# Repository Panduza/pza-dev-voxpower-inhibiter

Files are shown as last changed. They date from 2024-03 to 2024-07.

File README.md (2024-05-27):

# pza-dev-voxpower-inhibiter

The device will serve as the link between the Panduza platform and the Voxpower to command the inhibiters. The platform will use a serial communication with the board and the board will deliver 5V to the desired channel. 

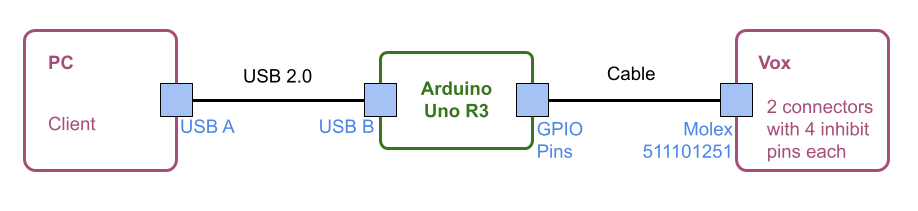
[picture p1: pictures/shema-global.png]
global representation of the product


### `[VOX_INHIB_0000_00]` - Board used

The board used **must** be an Arduino UNO R3

### `[VOX_INHIB_0010_00]` - Cables

The connection between the PC and the Arduino **must** be via an USB 2.0 A to B.

The connection between the Arduino and the Vox Power **must** be via simple cables linked to the connectors.

### `[VOX_INHIB_0020_00]` - Connectors

The connectors for the Vox Power **must** be :

| Manufacturer | Housing | Terminal  |
| :---: | :---: | :---: |
| Molex | 511101251 | 503948051 |

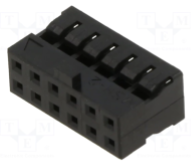
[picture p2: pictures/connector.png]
connector


### `[VOX_INHIB_0030_00]` - Pinout

The inhibiter pinout **must** be :

| Arduino | D2 | D3 | D4 | D5 | A0 | A1 | A2 | A3 | GND  |
| :--- | :--: | :--: | :--: | :--: | :--: | :--: | :--: | :--: | :--: |
| Vox | INH1 | INH2 | INH3 | INH4 | INH5 | INH6 | INH7 | INH8 | COM  |

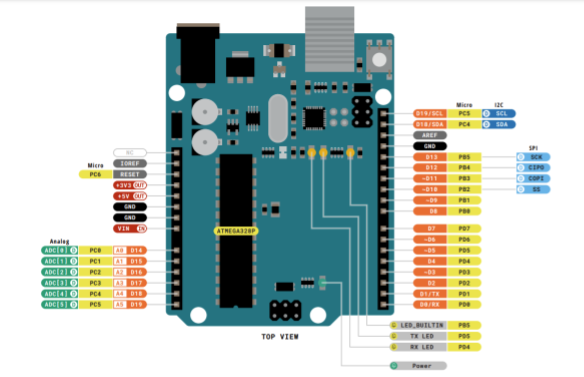
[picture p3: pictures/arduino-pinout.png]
arduino-pinout

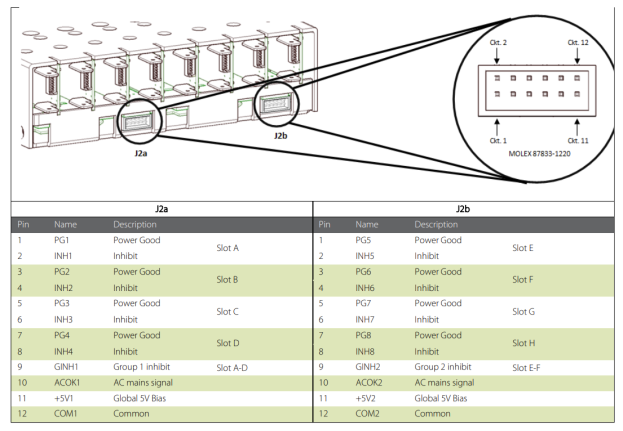
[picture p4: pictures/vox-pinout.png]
vox-pinout


### `[VOX_INHIB_0040_00]` - USB configuration

The USB configuration **must** be done with a serial link and a baud rate of 115200.

### `[VOX_INHIB_0050_10]` - Communication protocol

The protocol to specify the action (inhibit or enable or state) and the channel N **must** be :
```bash
"I" N

"E" N

"S" N
```

When receiving a "S" the Arduino **must** return the state "H" or "L" of the specified pin.
When changing the state, the Arduino **must** return the state "H" or "L" of the specified pin.

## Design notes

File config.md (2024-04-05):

# Conf

To use thee VoxposerInhibiter make sure that the /etc/panduza/tree.json contains\
\
tree.json
```bash
{
    "devices": [
        {
            "ref": "Panduza.VoxpowerInhibiter",
            "name": "test",
            "settings": 
            {
                "number_of_channel": 1
            }
        }
    ]
}
```

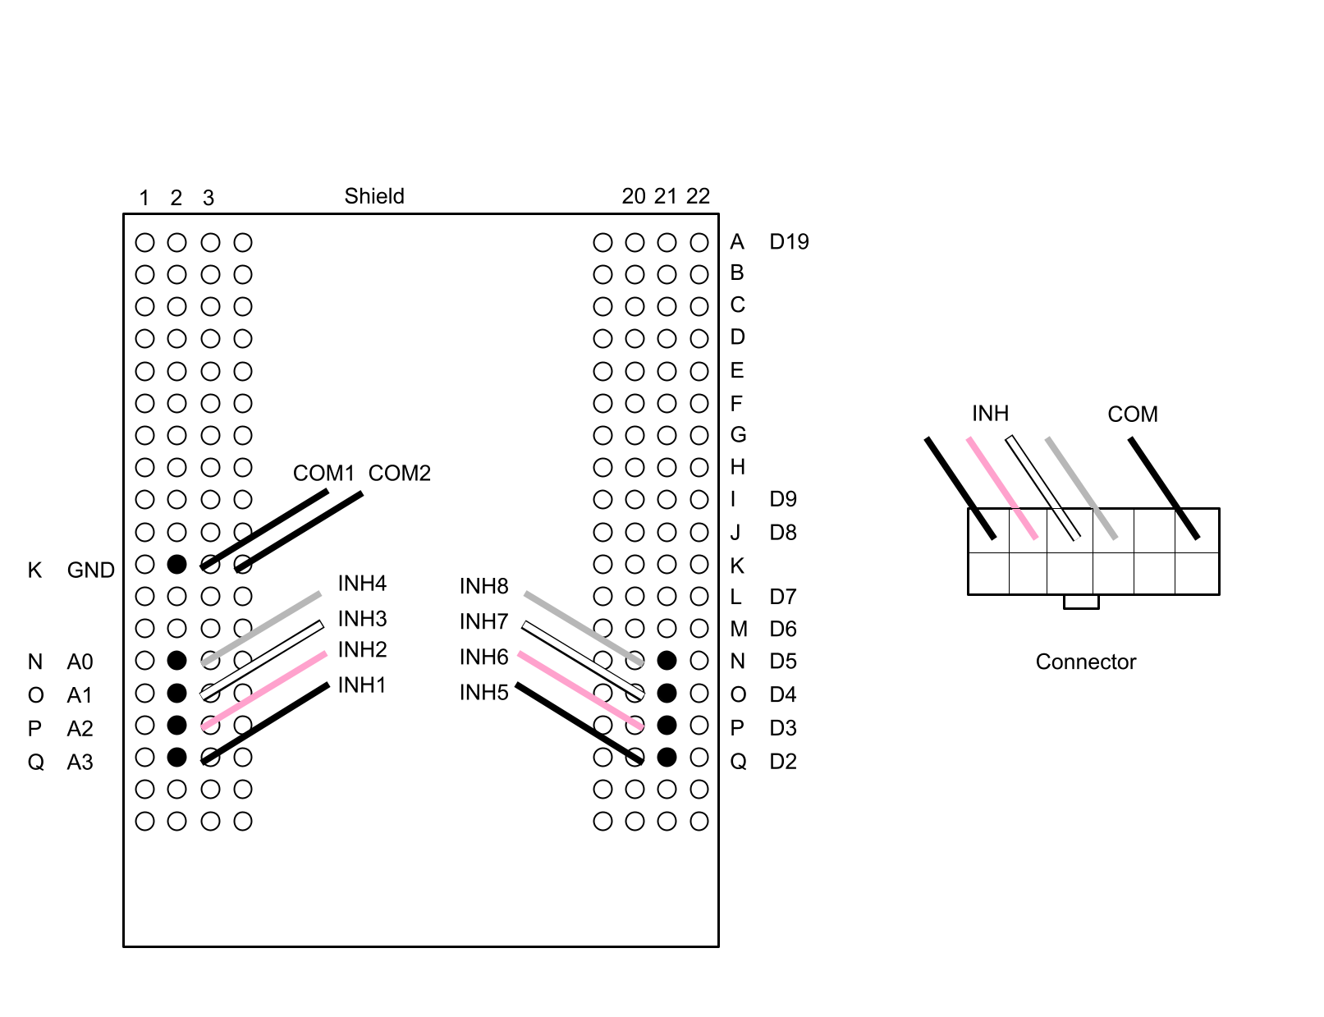
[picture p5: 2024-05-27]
pictures/cablage.png

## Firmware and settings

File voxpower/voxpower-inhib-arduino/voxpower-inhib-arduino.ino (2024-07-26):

#include <Arduino.h>

void setup() {

  // Set pin modes for channels
  for (int i = 2; i < 6; i++) {
    pinMode(i, OUTPUT);
  }
  for (int i = 14; i < 18; i++) {
    pinMode(i, OUTPUT);
  }


  // Start serial communication (default baud rate is 9600)
  Serial.begin(9600);
}

void loop() {
  if (Serial.available()) {
    // Receive a message with one character for command to set the pin state and one character for the id of the pin
    char command = Serial.read();
    int channel = Serial.readStringUntil('\n').toInt(); // Convert ASCII digit to integer
    channel += 1; // Channels 1 to 4 of the Voxpower corresponds to the Pin 2 to 5 of the arduino
    if (channel > 5) {
      channel += 8; // Cannels 5 to 8 of the Voxpower corresponds to the Pin 14 to 17 of the arduino
    }

    if (command == '?' ) {
      Serial.write("OK\n");

    } else if (command == 'I') {
      // Inhibit channel
      digitalWrite(channel, HIGH);

      Serial.write("OK\n");

    } else if (command == 'E') {
      // Enable channel
      digitalWrite(channel, LOW);
      
      Serial.write("OK\n");

    } else if (command == 'S') {
      // Get channel state

      if (digitalRead(channel) == HIGH) {
        Serial.write("H\n");
        
      } else {
        Serial.write("L\n");
      }
    }
    // Flush the buffer to immediately send the response
    Serial.flush();
  }
}

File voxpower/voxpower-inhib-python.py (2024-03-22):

import serial
import time

# Define the serial port and baud rate
arduino = serial.Serial(port='COM4', baudrate=115200, timeout=1)
time.sleep(2)

def inhibit(channel):
    """Sends an "I" command to activate the specified inhibit channel."""
    command = "I" + str(channel) + "\n"  # Construct the command string with "I" prefix
    arduino.write(command.encode())  # Encode and send the command
    print(command)

def enable(channel):
    """Sends an "E" command to dactivate the specified inhibit channel."""
    command = "E" + str(channel) + "\n"  # Construct the command string with "E" prefix
    arduino.write(command.encode())  # Encode and send the command

def get_pin_state(channel):
    """Sends an "S" command to request the state of the specified channel and reads the response."""
    command = "S" + str(channel) + "\n"  # Construct the command string with "S" prefix
    arduino.write(command.encode())  # Encode and send the command

    # Read response (assuming Arduino sends a single character 'H' or 'L')
    response = arduino.read().decode()
    if response == 'H':
        return True
    elif response == 'L':
        return False
    
print("start")
inhibit(9)
time.sleep(3)
print("stop")
enable(9)


"""
inhibit(8)
time.sleep(1)
enable(8)
time.sleep(1)
inhibit(9)
time.sleep(1)
enable(9)
"""

arduino.close()

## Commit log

2024-03-11 Arduino pinout
2024-03-11 connector and pinout pictures
2024-03-12 arduino pinout picture
2024-03-13 Arduino pinout correction
2024-03-13 Arduino pinout better picture
2024-03-15 added the pin state requirement
2024-03-21 added get channel state on the Arduino
2024-05-27 updated pinout and changing state speed problem solved (#5)
    * updated cabling schema
    * updated the pins used
    * updated Arduino pins used
    * removed debug comments
    * solved changing state speed problem
    ---------
    [voxpower-inhib-arduino.ino]
2024-05-29 6 sometimes the command is not received correctly (#7)
    * changed response to the platform
    * cleaned debug logs
    * Serial flush moved to avoid sending response when not supposed to and \n removed from the response as sometimes the message is split
    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
    [voxpower-inhib-arduino.ino]
2024-07-22 first shield proposition
    [Arduino_Uno.kicad_pcb, Arduino_Uno.kicad_sch]
2024-07-23 holes insted of pads for soldering
    [Arduino_Uno.kicad_pcb, Arduino_Uno.kicad_sch]
